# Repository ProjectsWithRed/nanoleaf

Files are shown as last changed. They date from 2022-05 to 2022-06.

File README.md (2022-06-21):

# NanoLeaf

A modular NanoLeaf lights that not only allows you to make any NanoLeaf shape using as many or as little segments as you want, but you can also use the same identical modular segments to create a 4-digit display, which can be used to display the time, temperature, humidity, or pretty much anything you want!

There is a [video](https://youtu.be/RalzwaIh_J4) associated with this repository/project, I highly recommend watching it before using this repo.

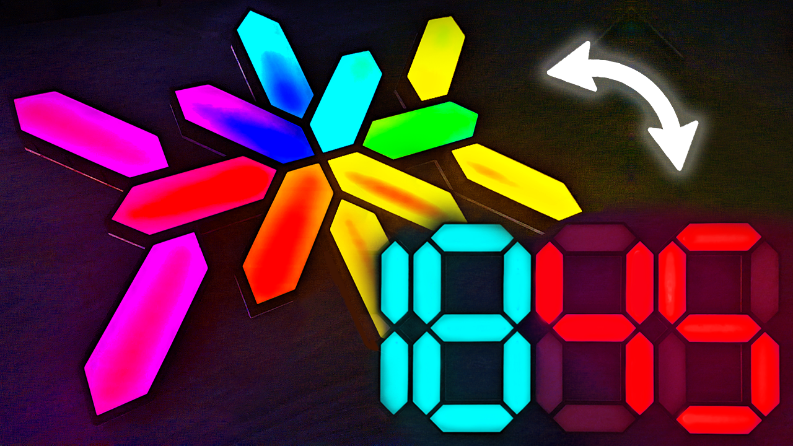
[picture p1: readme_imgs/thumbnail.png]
Video (https://youtu.be/RalzwaIh_J4 "NanoLeaf video")


# Code for any custom NanoLeaf shape

You simply just need to go to [here](https://install.wled.me/), press install and follow the instructions.

# Code for the 4-digit display

Keep in mind, that you don't need to do any of the steps below if you are just creating a NanoLeaf shape. For the code for any NanoLeaf shape, see [Code for any custom NanoLeaf shape](#Code-for-any-custom-NanoLeaf-shape).

Please note, in the video (time: `13:37`) I go through and show the exact steps on how to upload and use the code for the 4-digit display. Below is just a short text version.

1. Install [VSCode](https://code.visualstudio.com/).
2. In VSCode, install the `PlatformIO IDE` extension.
3. Clone/download this repo.
4. Open the `/WLED` directory in VSCode.
5. There are two changes you need to make before uploading the code:
    - In `WLED/platformio.ini`, under the `[env:esp32dev]` environment, change the `upload_port` to your micro-controller port.
    - In `WLED/usermods/NanoLeaf_Display/usermod_nanoleaf_display.h`, change the `ADDR_LEDS_PER_SEG` variable to the number of addressable LED sections there are in your LED strip. Below is an illustration to explain this further. In the example below, there are 3 sections, since there are 2 cut marks, so if you were to cut the LED strip on the cut marks, you will get 3 seperate sections, this is the number you need to set the `ADDR_LEDS_PER_SEG` variable to.
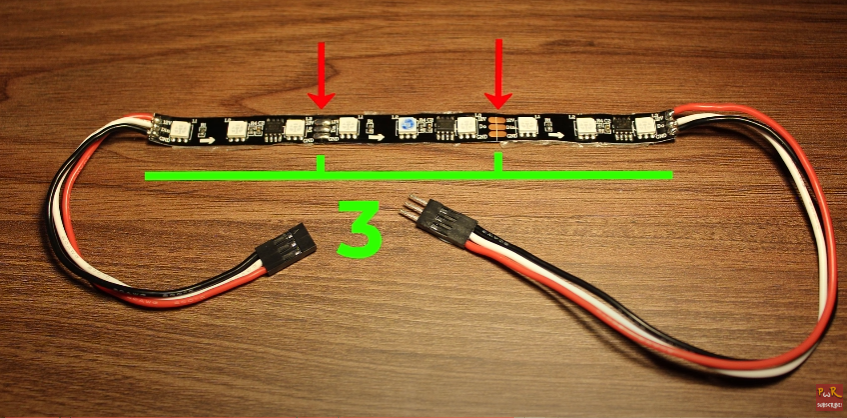
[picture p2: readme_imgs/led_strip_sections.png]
LED strip sections
    - 
6. Now you can upload the code.
7. For the setup you need to do on the phone and how to use the usermod settings to control the 4-digit display, refer to the video (time: `14:42`).

# Components

- [ESP32](https://www.amazon.co.uk/dp/B071P98VTG?ref_=cm_sw_r_cp_ud_dp_HRCFAE60FTX5CNG9CH61), for the micro-controller.
- [12V 8A](https://www.amazon.co.uk/dp/B0927KBGCP?ref_=cm_sw_r_cp_ud_dp_XS02N6BZ2QZ6SRK3ASNE), power supply.
- [LM2596](https://www.amazon.co.uk/dp/B077VW4BTY?ref_=cm_sw_r_cp_ud_dp_3PQZG5P3P4X3W8JCMQ5S) or any step down converter, to convert 12V to 5V for the ESP32. **Remember to use the screw on this component to adjust its output voltage to 5V using a voltmeter.**
- [LED strip](https://www.amazon.co.uk/dp/B01CNL6K52?ref_=cm_sw_r_cp_ud_dp_SHH2S3GJH9TY1MC4NM73), the specific one used in this project is the `WS2811` LED strip. Each segment requires 15cm long LED strip. For the 4-digit display, you will need at least 5 meters.
- 1000μF capacitor, across the LED strip.
- [A4 3mm matte opal acrylic sheets](https://plasticonline.co.uk/opal-frost-cast-acrylic-sheet.html) (x7), used to get the glowing effect. I recommend getting extra A4 sheets just in case something bad happens...
    - Refer to [Acrylic sheet shape](#Acrylic-sheet-shape) to see what shape you need to cut from the acrylic sheets.
- [DHT11](https://www.amazon.co.uk/dp/B06Y99X3NS?ref_=cm_sw_r_cp_ud_dp_4AR4MJQ16QP2X09JY0WM)(optional), used to get the temperature and humidity when using the 4-digit display.
- [Power switch](https://www.amazon.co.uk/dp/B01N2U8PK0?ref_=cm_sw_r_cp_ud_dp_JB40B1WS9YM9YZVZ7MQK), to turn on and off.
- M2 bolts, to attach the lid to the main housing part. They can be from 8mm to 12mm long.
- [20 AWG flexible silicon wires](https://www.amazon.co.uk/dp/B07G715HYY?ref_=cm_sw_r_cp_ud_dp_060MXTRE7K0QFSFT6WC1), for connecting segments together.
- [Dupont crimping tool](https://www.amazon.co.uk/dp/B07QNPZDTW?ref_=cm_sw_r_cp_ud_dp_D43ZQHCR3MZQAZ5CW36F), the tool used to make the dupont connectors.

# 3D models

Please refer to the `/3d_printing` directory.

# Acrylic sheet shape

To cut the acrylic to the correct shape, print this [A4 sheet](acrylic_sheet_reference.pdf). To ensure you have printed it to the correct scale, measure the top size of the shape, which should be `12 cm`.

# Wiring

## For any NanoLeaf shape
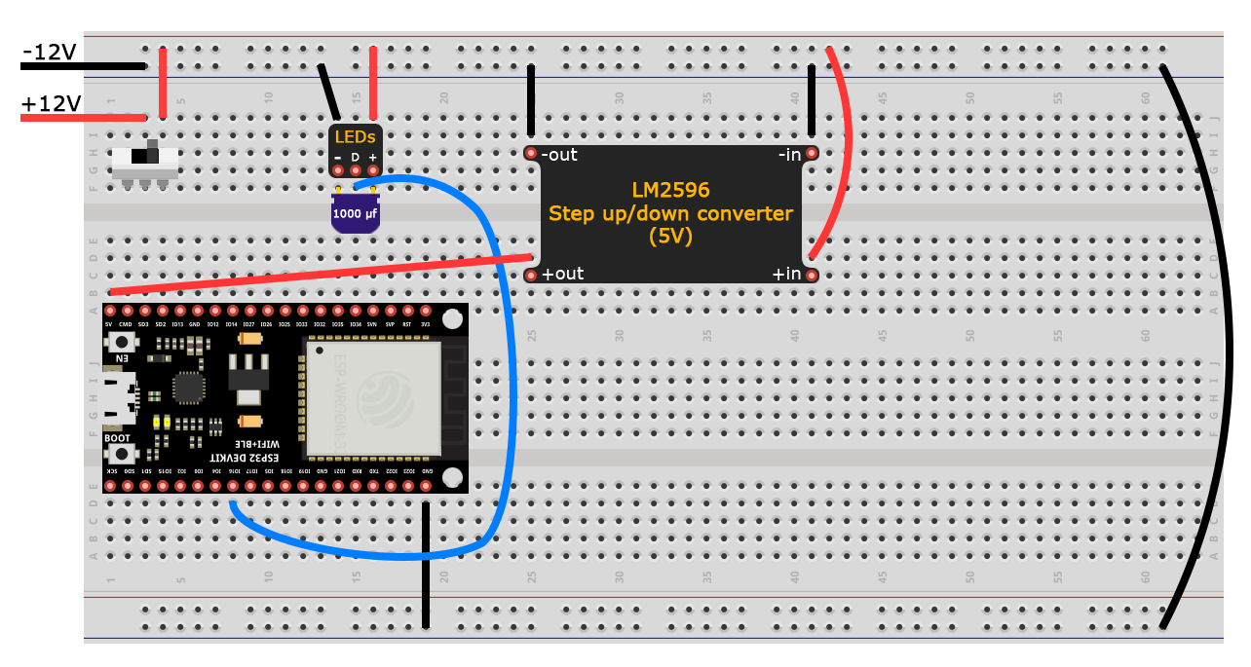
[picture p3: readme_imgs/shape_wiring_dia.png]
nanoleaf shape wiring diagram

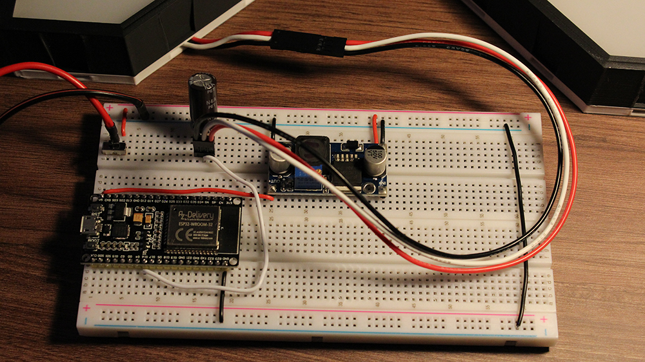
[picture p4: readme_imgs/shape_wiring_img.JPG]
nanoleaf shape wiring image


## For the 4-digit display

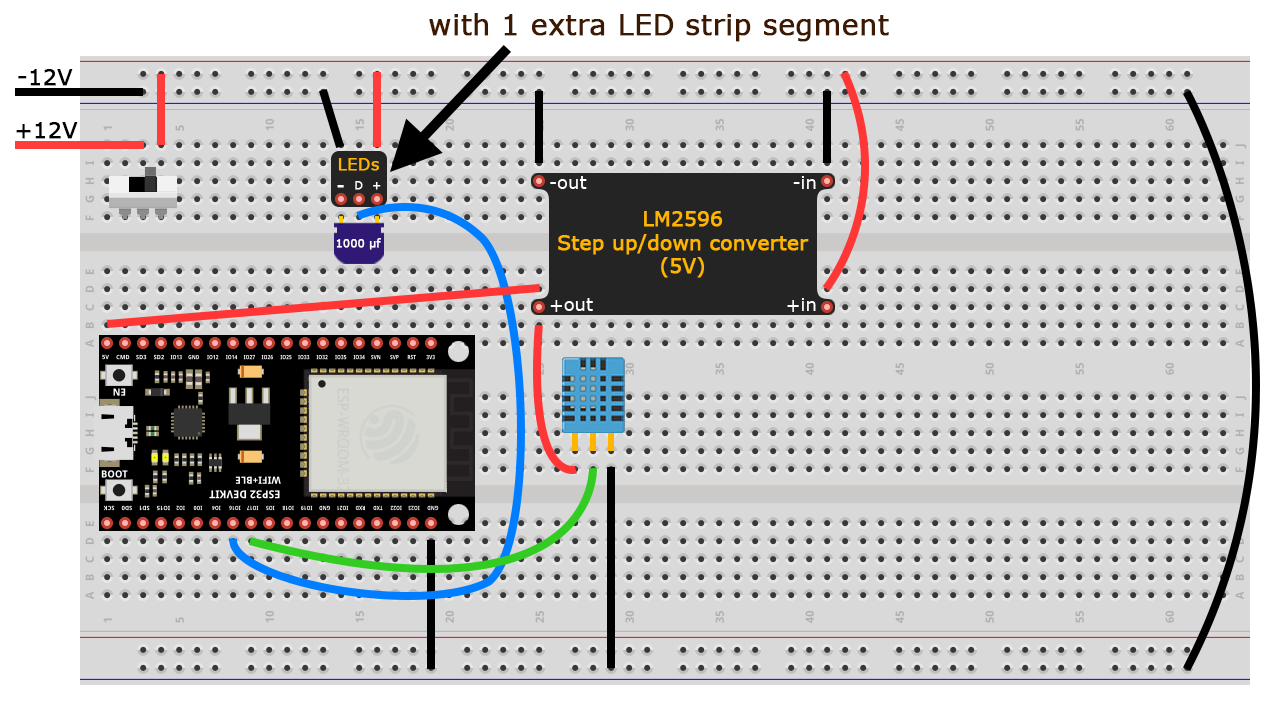
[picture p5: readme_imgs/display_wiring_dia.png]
4-digit display wiring diagram

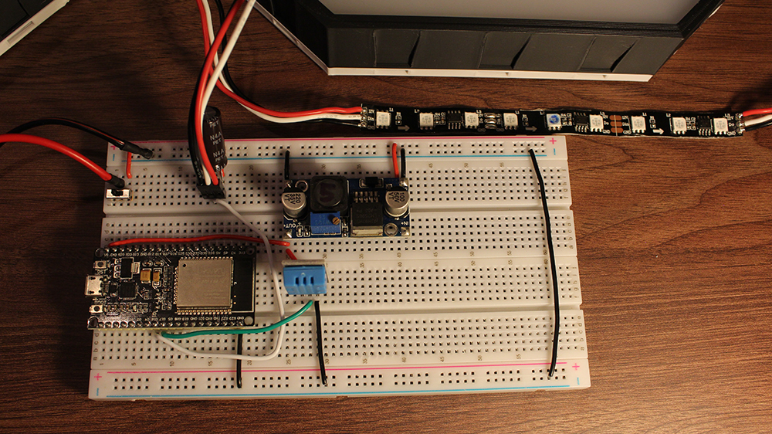
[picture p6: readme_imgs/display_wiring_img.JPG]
4-digit display wiring image


### 4-digit display segments wiring
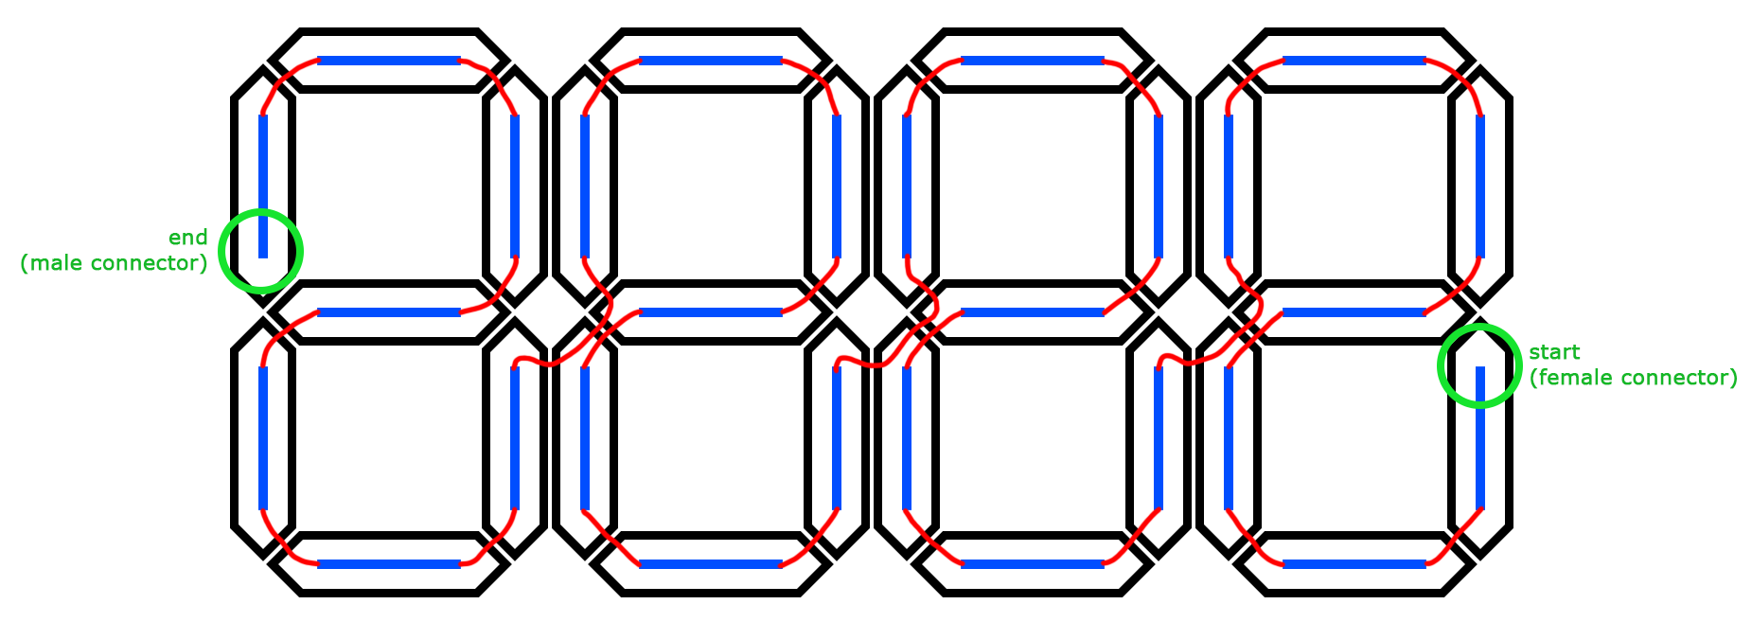
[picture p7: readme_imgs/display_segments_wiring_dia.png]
4-digit display segments wiring diagram

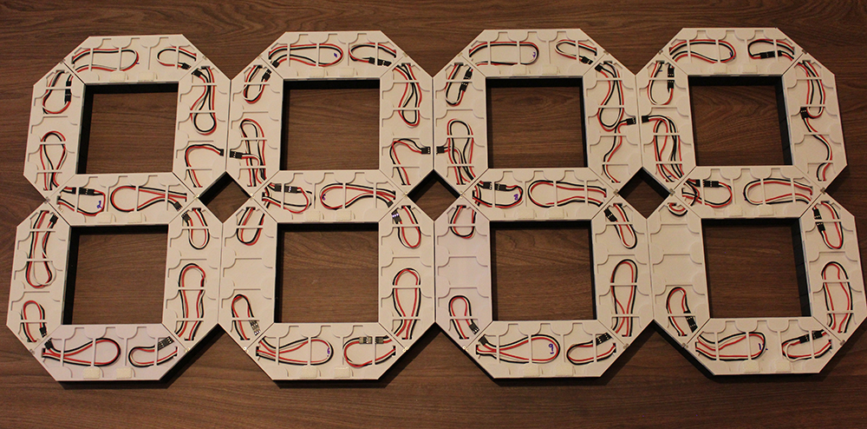
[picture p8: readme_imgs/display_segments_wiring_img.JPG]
4-digit display segments wiring image


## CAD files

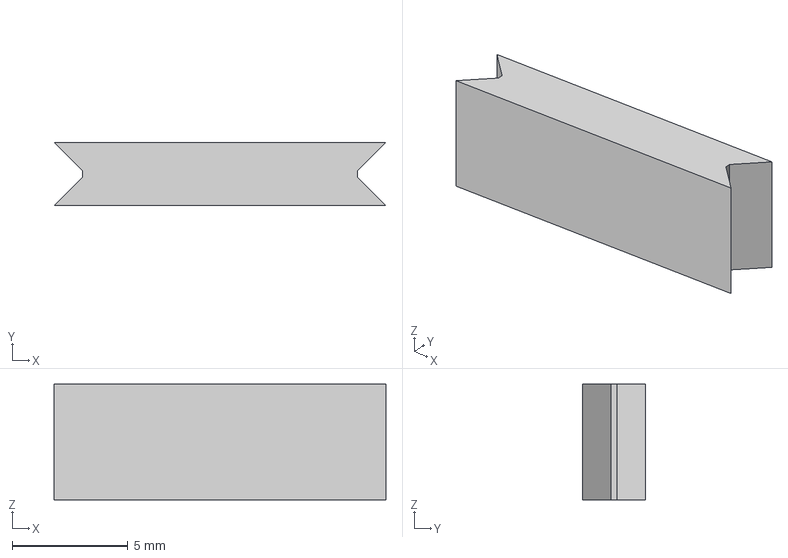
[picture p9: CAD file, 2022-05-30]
3d_printing/connector.3mf
14.3 x 2.73 x 5.00 mm

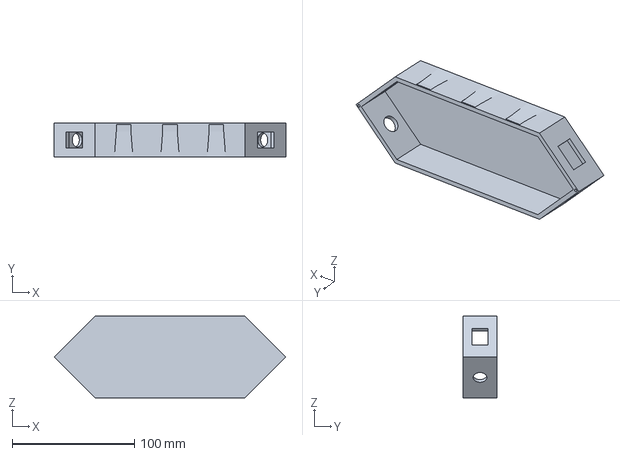
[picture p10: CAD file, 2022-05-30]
3d_printing/wiring_housing.3mf
189.6 x 27.6 x 66.8 mm

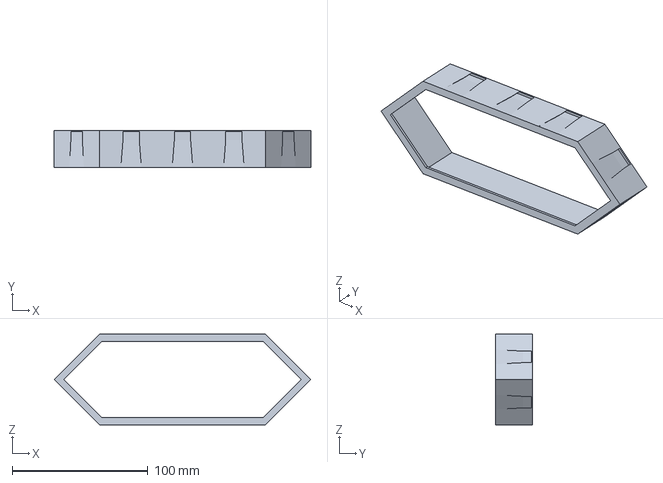
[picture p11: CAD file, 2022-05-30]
3d_printing/housing.3mf
189.6 x 27.6 x 66.8 mm

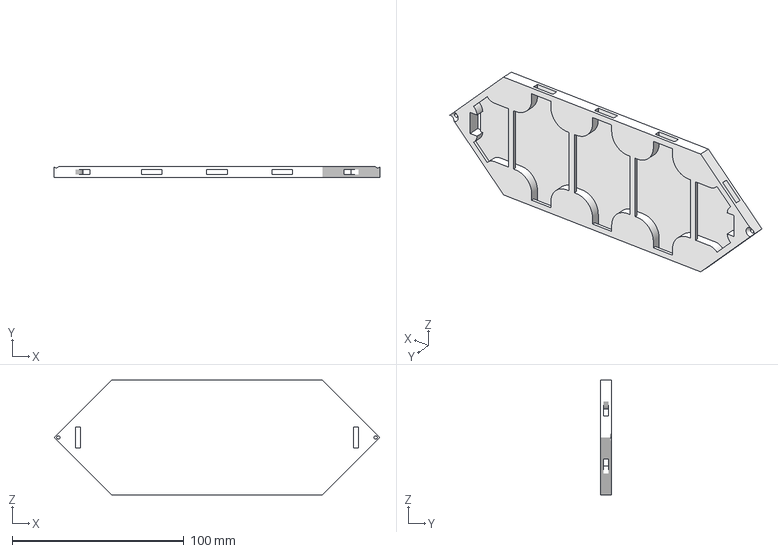
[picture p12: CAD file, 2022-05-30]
3d_printing/lid.3mf
189.6 x 6.20 x 66.8 mm

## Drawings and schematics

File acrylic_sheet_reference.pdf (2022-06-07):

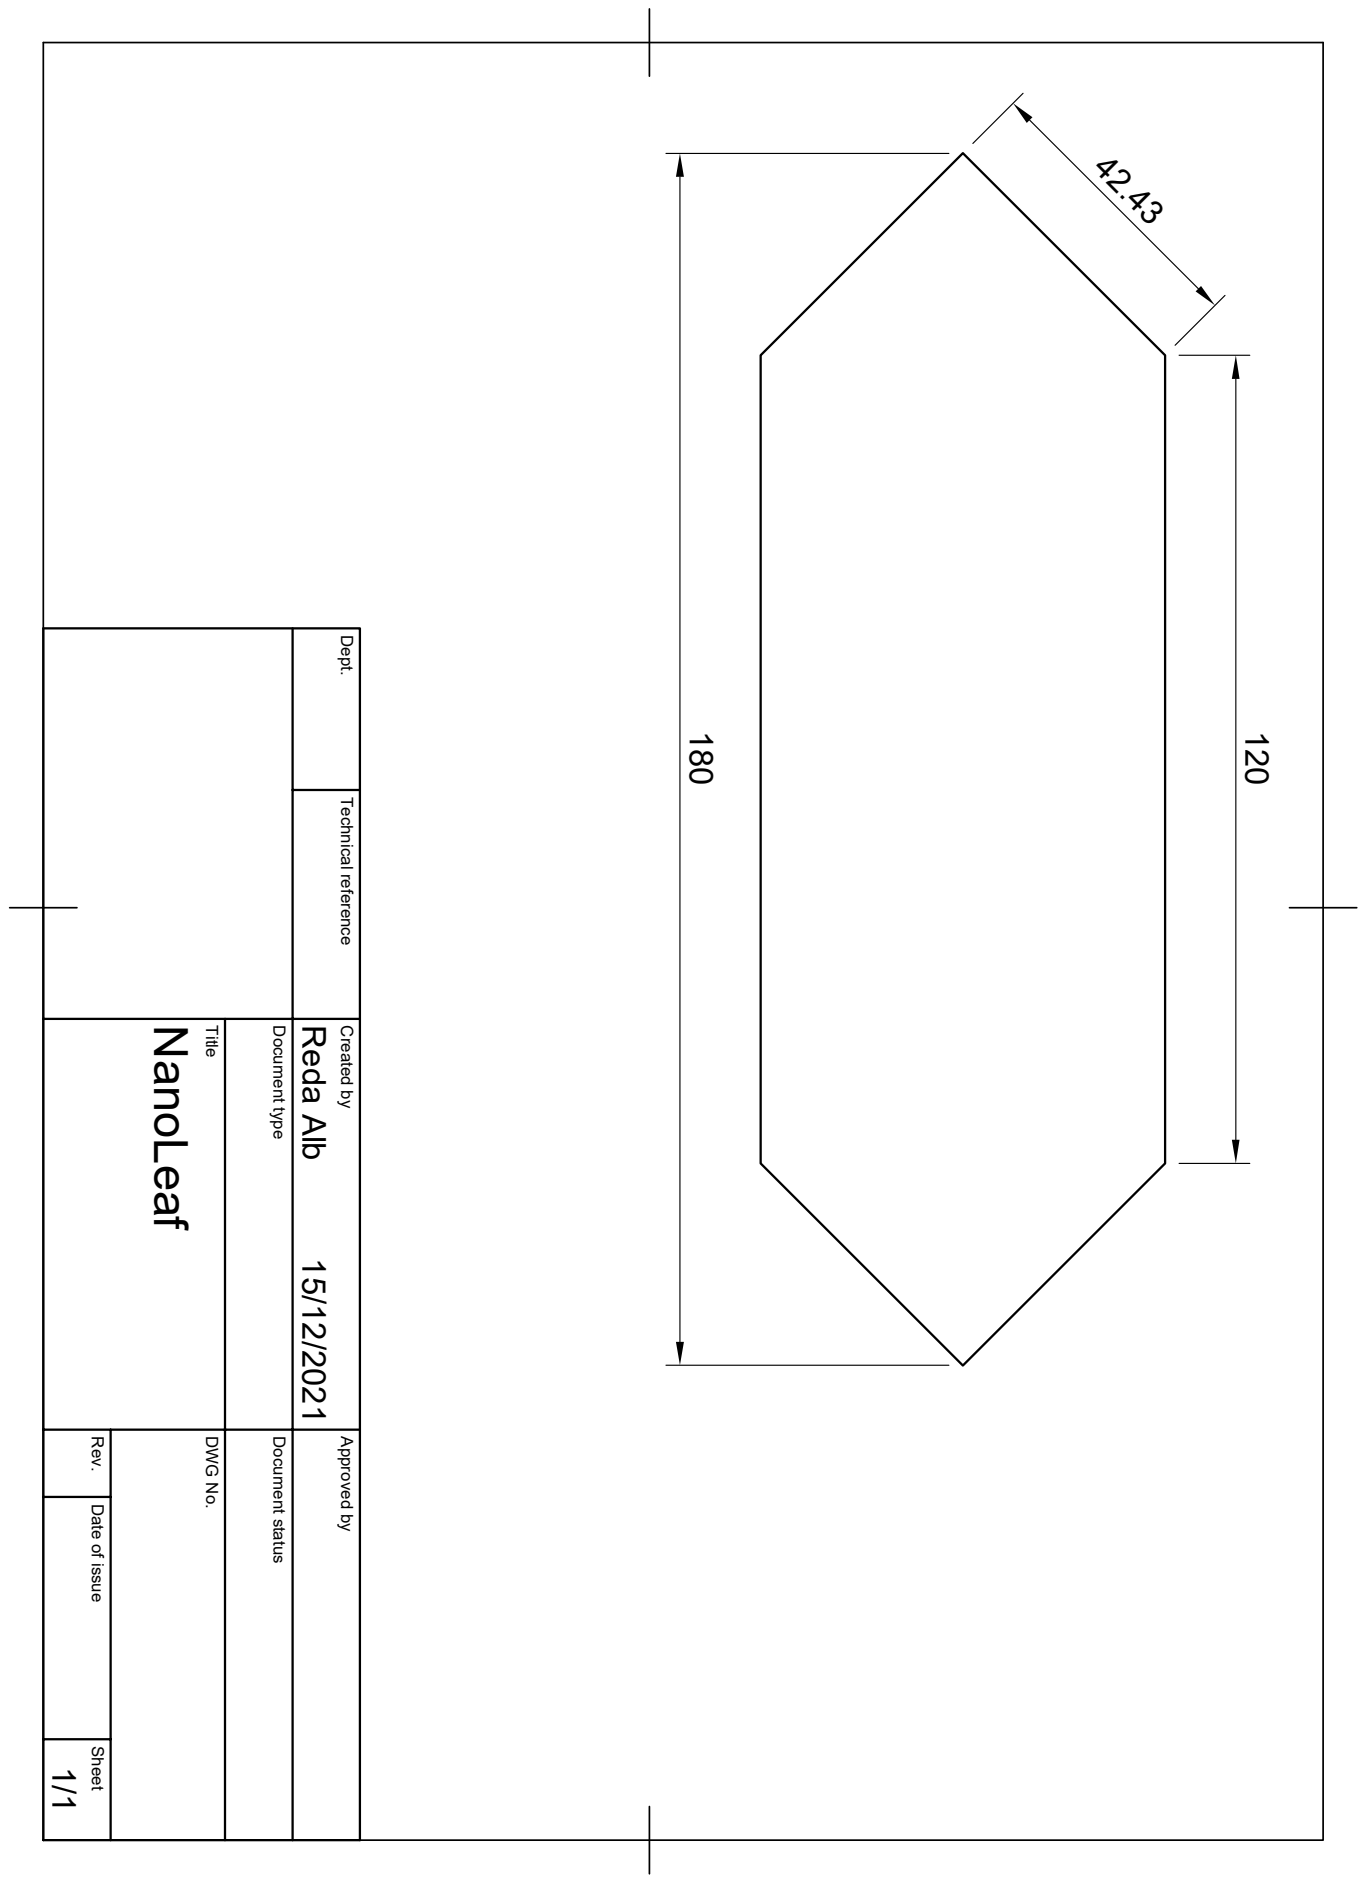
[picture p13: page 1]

Dept. Technical reference Created by Approved by Title DWG No. Document type Document status Rev. Date of issue Sheet 15/12/2021 1/1 NanoLeaf Reda Alb 120

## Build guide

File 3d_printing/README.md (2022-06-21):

# 3D printing

All the 3D printed parts used in this project.

- A segment is made up of two 3D printed parts, the housing and the lid.
- I recommend printing the lid in a white filament to reflect as much light as possible, however, black can also be used, as the difference is very minimal.
- Each segment requires roughly 75 grams of filament, 43 grams for the housing and 32 grams for the lid.

# 3D printing settings

- For the housing and lid parts, refer to `housing_lid_settings.curaprofile`.
- For the connector, refer to `connector_settings.curaprofile`.

# Images

## Housing
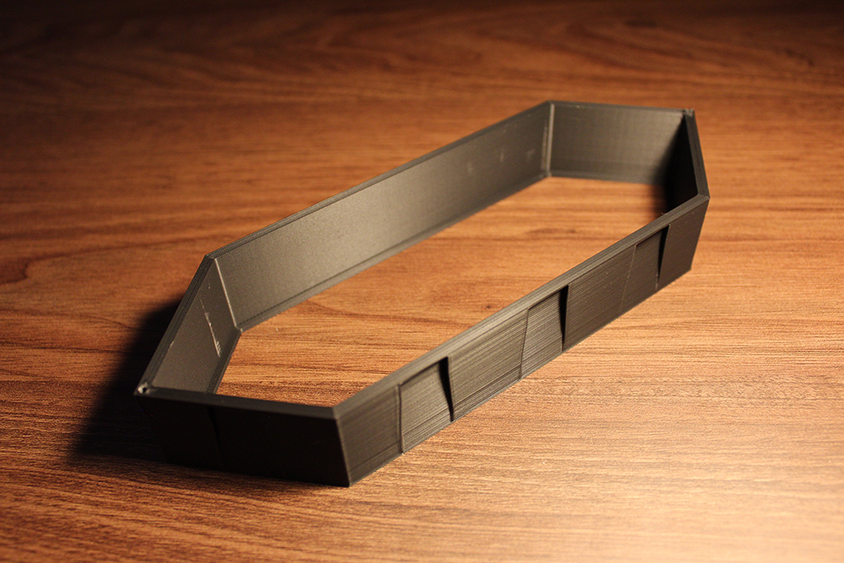
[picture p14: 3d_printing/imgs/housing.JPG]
housing


## Lid
| | |
|---|---|
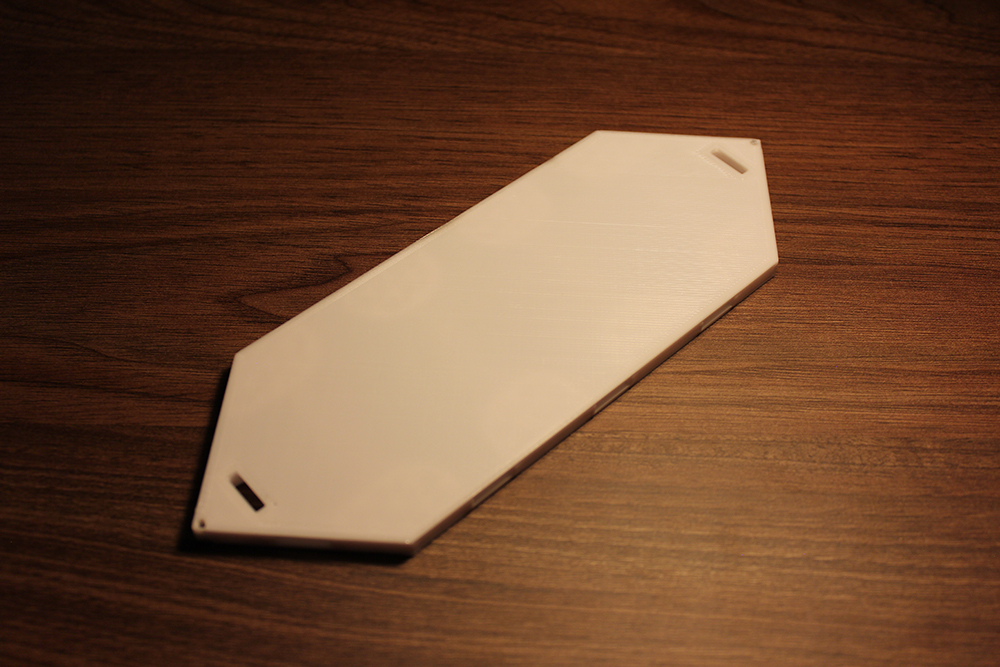
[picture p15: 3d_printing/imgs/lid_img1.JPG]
lid img1
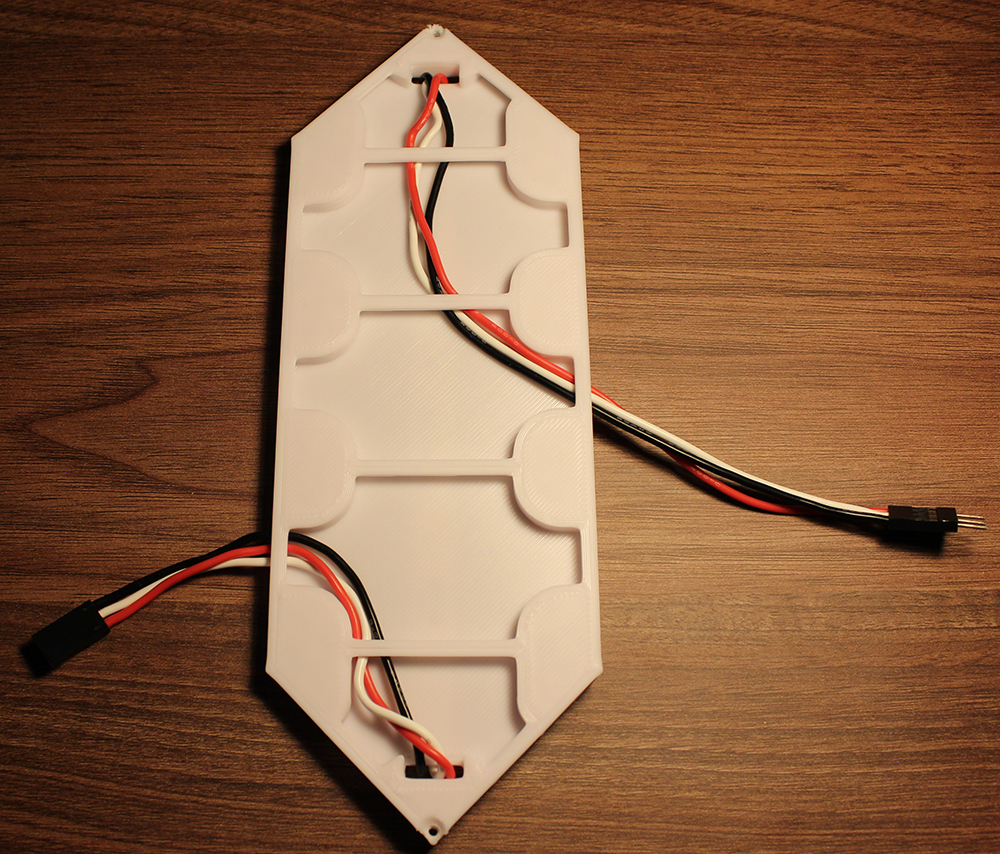
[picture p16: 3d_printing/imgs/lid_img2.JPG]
lid img2
|  |  |

## Connector
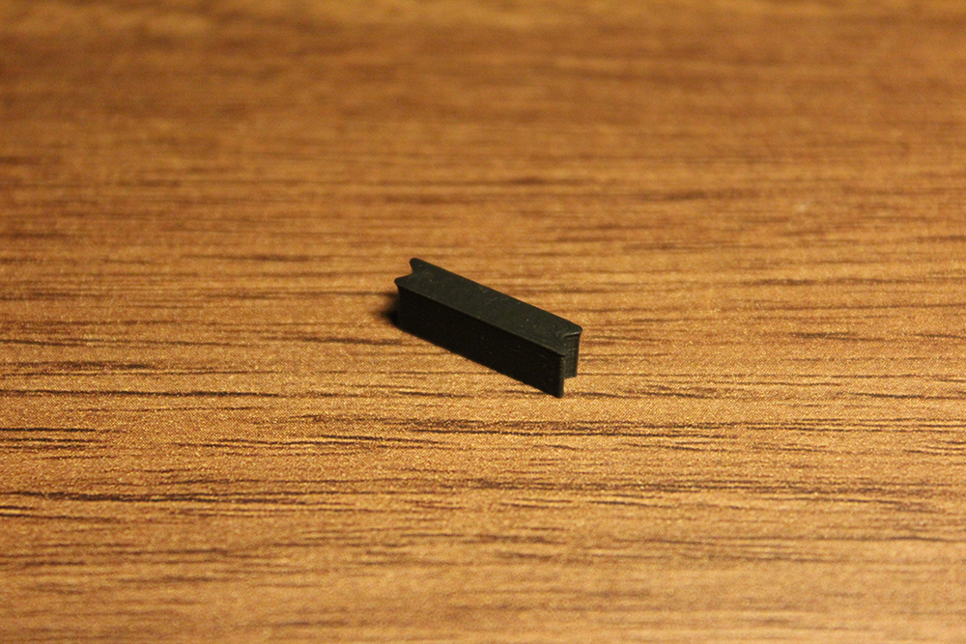
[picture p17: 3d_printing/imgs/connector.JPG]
connector


## Wiring housing
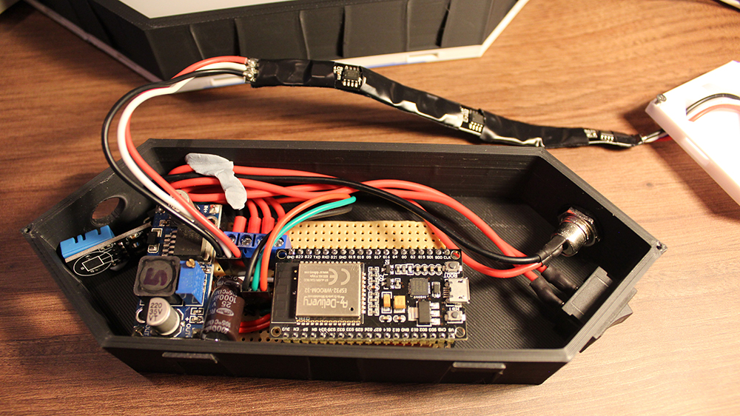
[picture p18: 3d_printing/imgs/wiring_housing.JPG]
wiring housing


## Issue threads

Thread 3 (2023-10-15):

12V 8A, power supply links to 12V 4A Power supply

FDahlke, 2023-10-15:
as title stated, currently the link for the power supply links to a 4A one, is this intended or did amazon change the product?

Closed 2023-11-30.

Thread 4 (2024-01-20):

Segments not working

DutchWorkX3D, 2024-01-20:
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
I have followed the manual and checked everything, uploaded the code to the esp32 but when turning on it only lights up the first digit fully and the second digit 2 segments.

In series mode the same.

It looks like it only turns on 87 leds instead of segmenting them.

I checked all the wiring and when turning on all leds by setting the amount of leds to 261 the turn on.
also checked the schematics and they are spot on with your manual.

ProjectsWithRed, 2024-01-21:
What is the exact issue you are facing? It looks like from the picture your LEDs are cut in segments of 1 LED, so you need to update the length accordingly which I think you found out to be 261. This is mentioned in the video at [10:56](https://youtu.be/RalzwaIh_J4?si=Q3jefhQwZ3zCQtOd&t=656).

LimeDexx, 2024-01-21:
Yes, I have exact the same length of led strips per segment as you have,
every box has one ledstrip with 9 leds and divided into 3 segments

28 x 3 + 3 = 87

28 times 9 leds = 252 + 9 (total individual addressable leds of 28 + the 1 extra strip of 9 as you discribe in your video)

LimeDexx, 2024-01-21:
Oh and sorry, Limedexx = Dutchworkx

LimeDexx, 2024-01-21:
Yes, with the setup as I described, how many leds should I fill in because now only 87 leds are on istead of all

ProjectsWithRed, 2024-01-21:
Your calculation is correct, however, for the extra strip, in your case it will just be 3 rather than 9. You just need 3 addressable leds as extra on the start.

LimeDexx, 2024-01-21:
Yes but in your video you have a strip of 9 and you set the total leds to 87
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

ProjectsWithRed, 2024-01-21:
In my case, every 3 LEDs are addressable as seen by the cuts, so 9 LEDs for me is only 3 addressable sections of the strip. I don't know exactly which LED strips you have but from the image you sent, it looks like each LED is separately addressable.

LimeDexx, 2024-01-21:
ok there we go, so in my case yes every light is addressable, what amount should I use then 9 sections per strip ?

ProjectsWithRed, 2024-01-21:
As many as you need to fit across the whole segment housing, and just update the variable `ADDR_LEDS_PER_SEG` found here `WLED/usermods/NanoLeaf_Display/usermod_nanoleaf_display.h` to match, more details can be found in the [readme](https://github.com/ProjectsWithRed/nanoleaf) regarding this.

LimeDexx, 2024-01-21:
Thank you very much for your help, it is working as it should be now :-)

LimeDexx, 2024-01-21:
by the way, I have remixed the box with printable diffuser so you will not need any other materials anymore.

ProjectsWithRed, 2024-01-22:
Perfect! Sounds good, if you want, push the 3D model to the repository of the diffuser and we can make it part of the 3D models, so other people may use it.

Closed 2024-02-10.

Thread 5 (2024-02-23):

Multi color print for diffuser

ctnate, 2024-02-23:
I am trying to print the diffuser in clear plastic with a multicolor printer - would it be possible to get the print housing file as a .step file for editing?

Thanks!

ProjectsWithRed, 2024-03-02:
Please find it attached 👍
[housing.zip](https://github.com/ProjectsWithRed/nanoleaf/files/14469310/housing.zip)

ctnate, 2024-03-20:
Thanks!  I think i have it nailed down, 4 layers of clear PETG, 2 layers of white PETG (make sure to get the cheap stuff like sunlu that is more white tinted).  Also use a circular pattern on the top white.  Also the FCOB RGB strips work really well for light diffusion.  I have attached my files.  I have included the Bambu setup as well as the ALIBRE files that I modified.
[nonleaf housing with lens.zip](https://github.com/ProjectsWithRed/nanoleaf/files/14675793/nonleaf.housing.with.lens.zip)

Any chance I can get the bottom part in STEP as well to try and make the colon that goes between the numbers?

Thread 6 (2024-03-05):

number of ICs, config problem

matitoprzechvj, 2024-03-05:
Hey, i am trying to make that digital clock, i have all segments already wired and set up. I'm using ws2812b leds which have 1 IC per 1 led, what number should i put here and in wled led count configuration to make it work? Every segment has strip containing 9 leds.

const int NUM_OF_SEGMENTS   = 28;   // Number of total segments the whole display contains.
---->  const int ADDR_LEDS_PER_SEG = 9;    // Number of addressable LEDs (ICs) per segment.
const int SEGS_PER_DIGIT    = 7;    // Number of segments that make up 1 digit.
const int NUM_DIGITS        = 10;   // Number of digits each 7 segment digit can display, 0-9.
-----> const int NUM_FIRST_LEDS    = 9;    // Number of first set of 3 addressable LEDs which are only used to set colours.

When im trying config as shown above only 3 segments and first strip that controlls the colours work

matitoprzechvj, 2024-03-05:
okey figured it out, i had to skip 6 first leds from first control strip, now i have different problem, digits are mirrored or reversed, for example when i manually set digits to 5 5 5 5 they are showing as 2 2 2 2 one way or another, but strangely digits like 1 3 are fine

ProjectsWithRed, 2024-03-06:
Hi,

You have chosen the correct numbers for most variables, but for the
NUM_FIRST_LEDS, it should still be 3, and you just need to make sure you
have 3 LEDs at the beginning.

What did you put as the length in the WLED app in the LED preferences
configuration? In your case, it should be (9*7*4) + 3 = 255, 9 LEDs per
segment, 7 segments per digit, 4 digits, plus the 3 in the beginning.

For the mirrored or reversed, did you follow the arrow correctly on the LED
strips? Also double check the wiring.

Thank you,
Reda

On Tue, 5 Mar 2024 at 23:03, matitoprzechvj ***@***.***>
wrote:

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

matitoprzechvj, 2024-03-09:
in my case, its perfectly fine when it is laying cable side up, its showing number correctly and everything works, ofc i need to flip it so then the numbers are upside down, picture attached, is there anything i can do in the code to idk reverse it or mirror, or i need to re-wire everything?
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

matitoprzechvj, 2024-03-11:
Okay, re wired everything and now it works fine, thanks

ProjectsWithRed, 2024-03-15:
That's amazing to hear! Good stuff!

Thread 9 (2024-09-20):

location of first LED segment (nanoloeaf clock)

fisherman-be, 2024-09-20:
Hello,

If I am not mistaken, the location of the first LED segment (female connector) in "readme_imgs/display_segments_wiring_dia.png" is different from the location in the photo "readme_imgs/display_segments_wiring_img.JPG". Also in the video, it seems to be in the lower leaf, not the upper.

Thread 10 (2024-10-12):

Package Exception after installing PlatformIO and opening the Nanoleaf folder

fisherman-be, 2024-10-12:
I printed and prepared the leafs and the electronics, now I wanted to load the code into the ESP32. I have been writing code for Windows  for ages, but I am absolutely no expert when it comes to Arduino code and its ecosystem.
I installed VS Code and installed the PlatformIO extension in the Extensions tab. Then I dragged the Nanoloeaf folder into VS Code.
After that, it takes a few seconds before I see the following output:

Resolving esp32dev dependencies...
Library Manager: Installing git+https://github.com/Aircoookie/ESPAsyncWebServer.git @ ~2.0.4
git version 2.47.0.windows.1
Cloning into 'C:\Users\******\.platformio\.cache\tmp\pkg-installing-oiccdyf0'...

PackageException: Package version 2.3.0+sha.00be156 doesn't satisfy requirements ~2.0.4 based on PackageMetadata <type=library name=ESPAsyncWebServerWLED version=2.3.0+sha.00be156 spec={'owner': None, 'id': None, 'name': 'ESPAsyncWebServer', 'requirements': '~2.0.4', 'uri': 'git+https://github.com/Aircoookie/ESPAsyncWebServer.git'}

How can I resolve this to be able to upload the code?

fisherman-be, 2024-10-13:
Never mind, I fixed it after some googling, trial and error and finally using a tag.

Closed 2024-10-13.

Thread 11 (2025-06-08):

Segments not working

LutherKaine, 2025-06-08:
First of all, what a cool project.

I wasn't sure if I should re-open the last not working issue from Dutch, as it was closed, so I opted for opening a new issue, although mine is very similar.

Again, first of all, I'm not very experienced with electronics, but always eager to learn.

As you can see in the below image, not all segments of the clock are working as intended. Minutes work fine, every segments lights up if the time is right for it. But the hours aren't working properly, only one segment is lighting up:

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

Only 15 Segments of the clock are working, and no matter what I do, it always stays like that. I triple checked the connections, replaced pretty much all the segments with that one in the orange (violet) spot, but it will always only light up one of the hour segments of the clock.

LED-Strip is the same as you used, 3 LEDs per controller, so 9 LEDs per digit plus the one you mentioned to add extra for controlling brings the length to 87 in WLED app.

I went countless times over the schematics and redid them times and times again following your manual to the letter, but nothing changes. I also used several ESP32s and flashed each one a couple times, but again nothing changes.

I hope that you can direct me to the right solution.

Thank you very much in advance for your help.

Greetings Luther

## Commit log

2022-05-30 Add 3d models
    [connector.3mf, housing.3mf, lid.3mf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]
2022-05-30 Add wiring diagrams and images
2022-06-21 Add 3d print settings
